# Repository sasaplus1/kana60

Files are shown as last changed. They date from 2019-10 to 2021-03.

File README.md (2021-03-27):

# kana60



JP layout 60% mechanical keyboard

<p align="center">
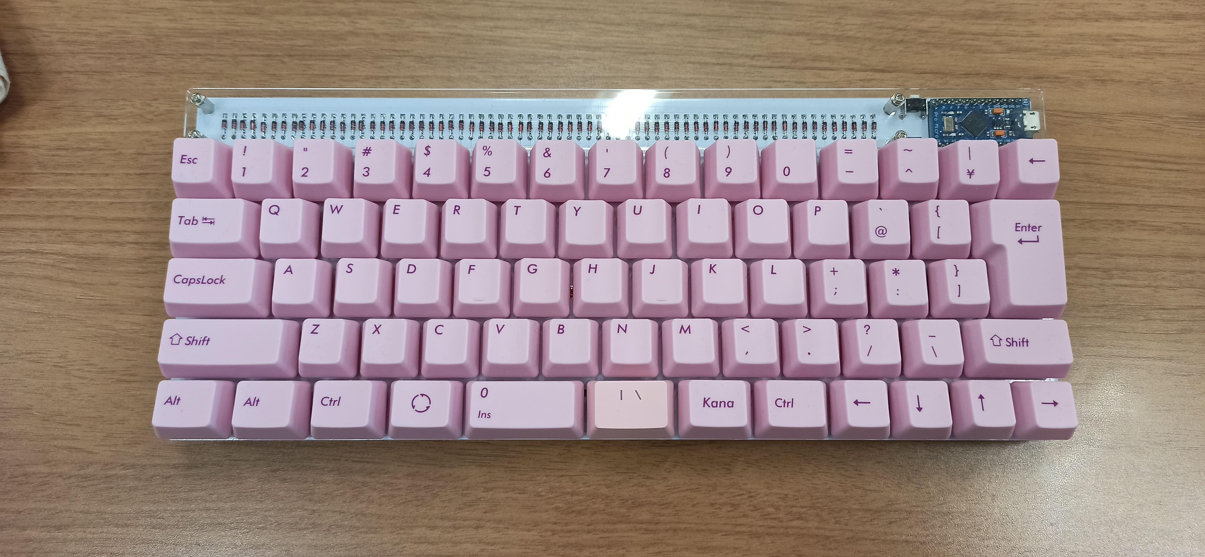
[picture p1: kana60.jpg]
kana60 keyboard
  
</p>

Keycaps: [FILCO FKCS108NMP](https://www.amazon.co.jp/dp/B07SR3NHXY/) and another 1 keycap (At bottom of N key).

QMK Firmware: [sasaplus1/qmk_firmware](https://github.com/qmk/qmk_firmware/compare/master...sasaplus1:kana60-test)

## How to verify checksums

```console
$ ls -1
kana60-acrylic-plates.zip
kana60-sha256sum.txt
kana60-top-plate.zip
kana60.zip
$ shasum --check kana60-sha256sum.txt
kana60-acrylic-plates.zip: OK
kana60.zip: OK
kana60-top-plate.zip: OK
```

## How to release

remove dist files:

```console
$ make clean
```

generate some files:

- open `kana60.kicad_pcb` and generate gerber files and drill files, via: `plot...`
- open `kana60-top-plate.kicad_pcb` and generate gerber files and drill files, via: `plot...`
- open `kana60-acrylic-plates.kicad_pcb` and generate PDF files, via: `plot...`

generate zip files and checksum file:

```console
$ make build create_checksum
```

verify zip files:

```console
$ make info
zipinfo dist/kana60-acrylic-plates/kana60-acrylic-plates.zip
Archive:  dist/kana60-acrylic-plates/kana60-acrylic-plates.zip
Zip file size: 22152 bytes, number of entries: 2
-rw-r--r--  3.0 unx     3150 bx defN 19-Oct-27 17:44 kana60-acrylic-plates-main.pdf
-rw-r--r--  3.0 unx    20236 bx defN 19-Oct-27 17:44 kana60-acrylic-plates-dimensions.pdf
2 files, 23386 bytes uncompressed, 21742 bytes compressed:  7.0%
zipinfo dist/kana60/kana60.zip
Archive:  dist/kana60/kana60.zip
Zip file size: 455650 bytes, number of entries: 9
-rw-r--r--  3.0 unx   807098 tx defN 19-Oct-27 17:44 kana60.GBL
-rw-r--r--  3.0 unx   293239 tx defN 19-Oct-27 17:44 kana60.GBS
-rw-r--r--  3.0 unx    49400 tx defN 19-Oct-27 17:44 kana60.GBO
-rw-r--r--  3.0 unx      980 tx defN 19-Oct-27 17:44 kana60.GML
-rw-r--r--  3.0 unx   522285 tx defN 19-Oct-27 17:44 kana60.GTL
-rw-r--r--  3.0 unx   293239 tx defN 19-Oct-27 17:44 kana60.GTS
-rw-r--r--  3.0 unx    88481 tx defN 19-Oct-27 17:44 kana60.GTO
-rw-r--r--  3.0 unx     4210 tx defN 19-Oct-27 17:44 kana60-NPTH.TXT
-rw-r--r--  3.0 unx    11536 tx defN 19-Oct-27 17:44 kana60.TXT
9 files, 2070468 bytes uncompressed, 454286 bytes compressed:  78.1%
zipinfo dist/kana60-top-plate/kana60-top-plate.zip
Archive:  dist/kana60-top-plate/kana60-top-plate.zip
Zip file size: 93042 bytes, number of entries: 9
-rw-r--r--  3.0 unx   201454 tx defN 19-Oct-27 17:44 kana60-top-plate.GBL
-rw-r--r--  3.0 unx     5359 tx defN 19-Oct-27 17:44 kana60-top-plate.GBS
-rw-r--r--  3.0 unx    11104 tx defN 19-Oct-27 17:44 kana60-top-plate.GBO
-rw-r--r--  3.0 unx    19886 tx defN 19-Oct-27 17:44 kana60-top-plate.GML
-rw-r--r--  3.0 unx   201454 tx defN 19-Oct-27 17:44 kana60-top-plate.GTL
-rw-r--r--  3.0 unx     5359 tx defN 19-Oct-27 17:44 kana60-top-plate.GTS
-rw-r--r--  3.0 unx      506 tx defN 19-Oct-27 17:44 kana60-top-plate.GTO
-rw-r--r--  3.0 unx      296 tx defN 19-Oct-27 17:44 kana60-top-plate-NPTH.TXT
-rw-r--r--  3.0 unx      388 tx defN 19-Oct-27 17:44 kana60-top-plate.TXT
9 files, 445806 bytes uncompressed, 91498 bytes compressed:  79.5%
```

push tag to GitHub and create Release:

```console
$ git tag 1.0
$ git push origin 1.0
```

upload files:

- kana60-acrylic-plates.zip
- kana60-sha256sum.txt
- kana60-top-plate.zip
- kana60.zip

## License

The MIT license.

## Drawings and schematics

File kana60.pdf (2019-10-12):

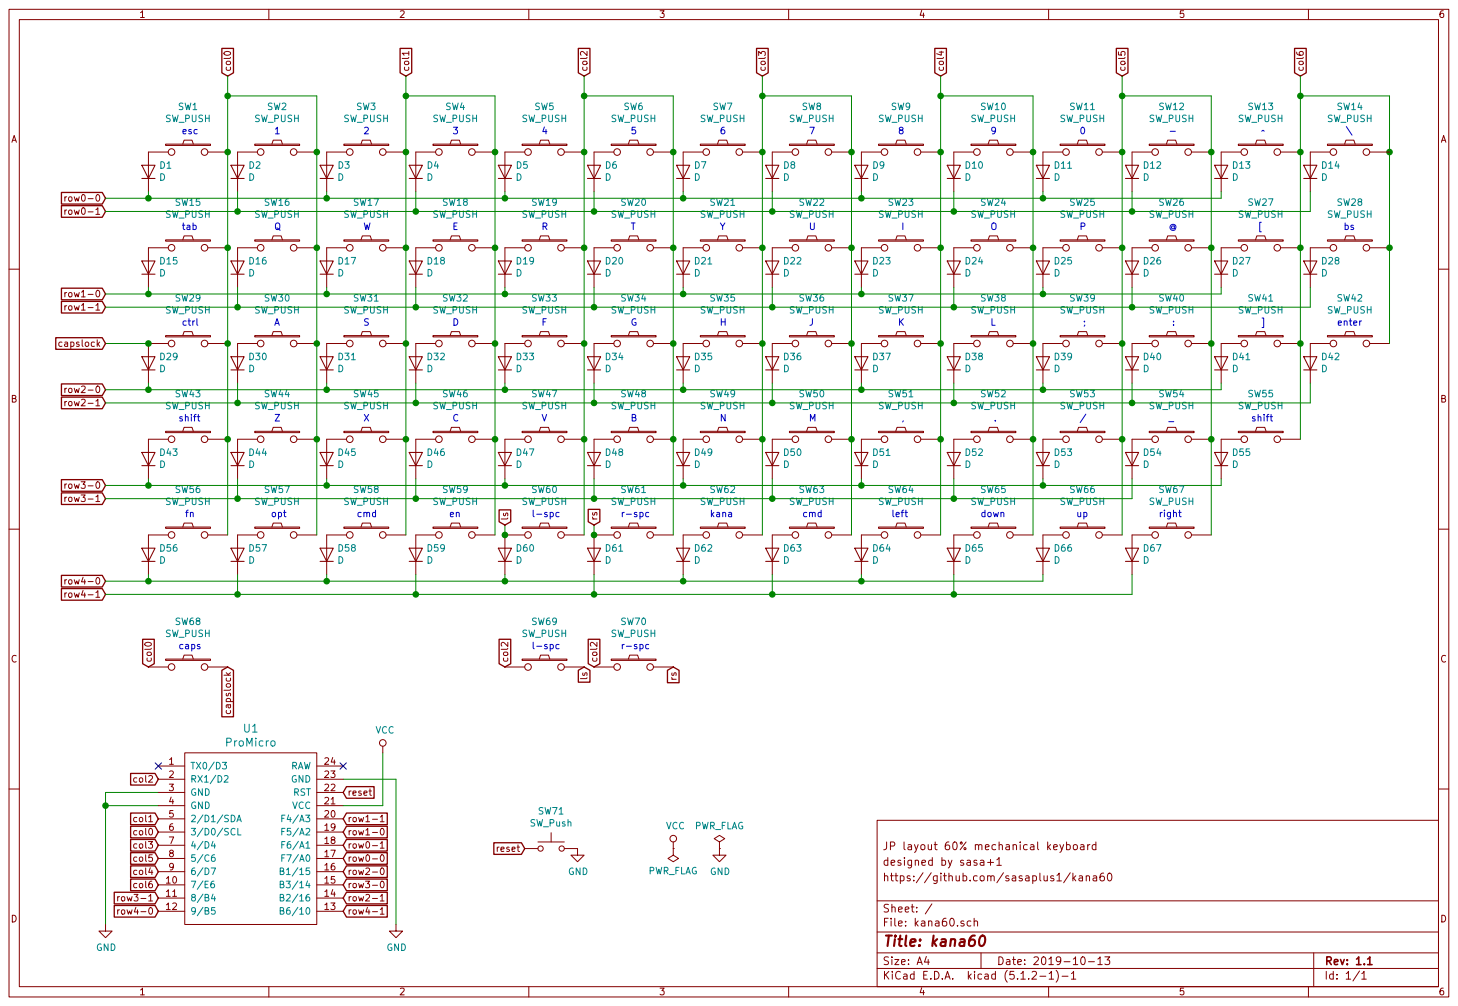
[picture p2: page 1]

JP layout 60% mechanical keyboard
designed by sasa+1
File: kana60.sch Sheet: / https://github.com/sasaplus1/kana60

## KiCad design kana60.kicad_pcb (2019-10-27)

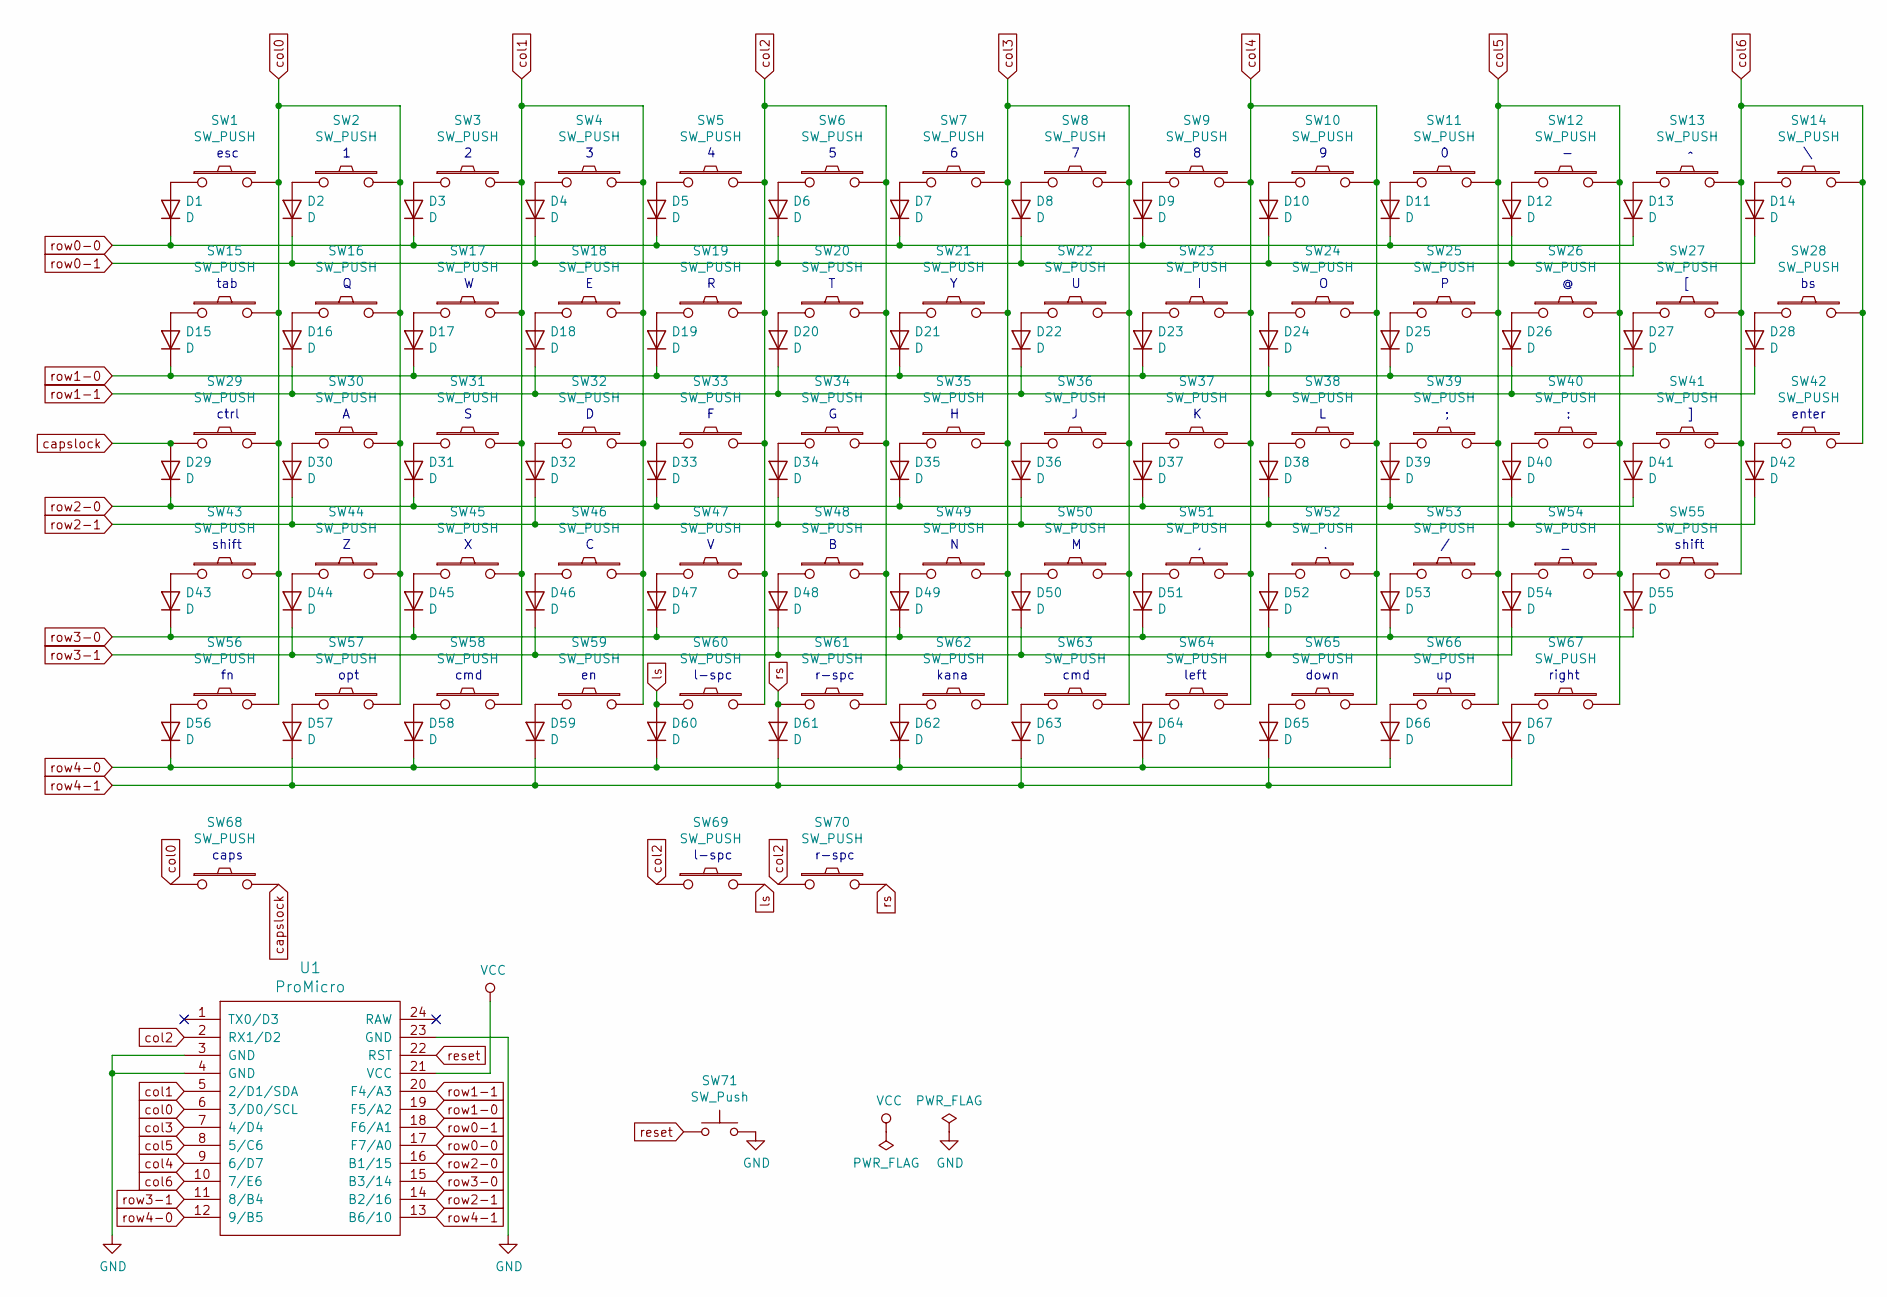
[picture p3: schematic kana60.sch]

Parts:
D1, D2, D3, D4, D5, D6, D7, D8, D9, D10, D11, D12, D13, D14, D15, D16, D17, D18, D19, D20, D21, D22, D23, D24, D25, D26, D27, D28, D29, D30, D31, D32, D33, D34, D35, D36, D37, D38, D39, D40, D41, D42, D43, D44, D45, D46, D47, D48, D49, D50, D51, D52, D53, D54, D55, D56, D57, D58, D59, D60, D61, D62, D63, D64, D65, D66, D67: D; diode
SW1, SW2, SW3, SW4, SW5, SW6, SW7, SW8, SW9, SW10, SW11, SW12, SW13, SW14, SW16, SW17, SW18, SW19, SW20, SW21, SW22, SW23, SW24, SW25, SW26, SW27, SW28, SW30, SW31, SW32, SW33, SW34, SW35, SW36, SW37, SW38, SW39, SW40, SW41, SW44, SW45, SW46, SW47, SW48, SW49, SW50, SW51, SW52, SW53, SW54, SW61, SW64, SW65, SW66, SW67, SW68, SW69: SW_PUSH; Hybrid_PCB_100H
SW15: SW_PUSH; Hybrid_PCB_150H
SW29, SW55: SW_PUSH; Hybrid_PCB_175H
SW42, SW43, SW60, SW70: SW_PUSH; Hybrid_PCB_200H
SW56, SW57, SW58, SW59, SW62, SW63: SW_PUSH; Hybrid_PCB_125H
SW71: SW_Push; SW_Tactile_SPST_Angled_MJTP1117
U1: ProMicro; ArduinoProMicro

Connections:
GND: SW71.2, U1.3 (GND), U1.4 (GND), U1.23 (GND)
unnamed: D1.2 (A), SW1.1
unnamed: D2.2 (A), SW2.1
unnamed: D3.2 (A), SW3.1
unnamed: D4.2 (A), SW4.1
unnamed: D5.2 (A), SW5.1
unnamed: D6.2 (A), SW6.1
unnamed: D7.2 (A), SW7.1
unnamed: D8.2 (A), SW8.1
unnamed: D9.2 (A), SW9.1
unnamed: D10.2 (A), SW10.1
unnamed: D11.2 (A), SW11.1
unnamed: D12.2 (A), SW12.1
unnamed: D13.2 (A), SW13.1
unnamed: D14.2 (A), SW14.1
unnamed: D15.2 (A), SW15.1
unnamed: D16.2 (A), SW16.1
unnamed: D17.2 (A), SW17.1
unnamed: D18.2 (A), SW18.1
unnamed: D19.2 (A), SW19.1
unnamed: D20.2 (A), SW20.1
unnamed: D21.2 (A), SW21.1
unnamed: D22.2 (A), SW22.1
unnamed: D23.2 (A), SW23.1
unnamed: D24.2 (A), SW24.1
unnamed: D25.2 (A), SW25.1
unnamed: D26.2 (A), SW26.1
unnamed: D27.2 (A), SW27.1
unnamed: D28.2 (A), SW28.1
unnamed: D30.2 (A), SW30.1
unnamed: D31.2 (A), SW31.1
unnamed: D32.2 (A), SW32.1
unnamed: D33.2 (A), SW33.1
unnamed: D34.2 (A), SW34.1
unnamed: D35.2 (A), SW35.1
unnamed: D36.2 (A), SW36.1
unnamed: D37.2 (A), SW37.1
unnamed: D38.2 (A), SW38.1
unnamed: D39.2 (A), SW39.1
unnamed: D40.2 (A), SW40.1
unnamed: D41.2 (A), SW41.1
unnamed: D42.2 (A), SW42.1
unnamed: D43.2 (A), SW43.1
unnamed: D44.2 (A), SW44.1
unnamed: D45.2 (A), SW45.1
unnamed: D46.2 (A), SW46.1
unnamed: D47.2 (A), SW47.1
unnamed: D48.2 (A), SW48.1
unnamed: D49.2 (A), SW49.1
unnamed: D50.2 (A), SW50.1
unnamed: D51.2 (A), SW51.1
unnamed: D52.2 (A), SW52.1
unnamed: D53.2 (A), SW53.1
unnamed: D54.2 (A), SW54.1
unnamed: D55.2 (A), SW55.1
unnamed: D56.2 (A), SW56.1
unnamed: D57.2 (A), SW57.1
unnamed: D58.2 (A), SW58.1
unnamed: D59.2 (A), SW59.1
unnamed: D62.2 (A), SW62.1
unnamed: D63.2 (A), SW63.1
unnamed: D64.2 (A), SW64.1
unnamed: D65.2 (A), SW65.1
unnamed: D66.2 (A), SW66.1
unnamed: D67.2 (A), SW67.1
VCC: U1.21 (VCC)
capslock: D29.2 (A), SW29.1, SW68.2
col0: SW1.2, SW2.2, SW15.2, SW16.2, SW29.2, SW30.2, SW43.2, SW44.2, SW56.2, SW57.2, SW68.1, U1.6 (3/D0/SCL)
col1: SW3.2, SW4.2, SW17.2, SW18.2, SW31.2, SW32.2, SW45.2, SW46.2, SW58.2, SW59.2, U1.5 (2/D1/SDA)
col2: SW5.2, SW6.2, SW19.2, SW20.2, SW33.2, SW34.2, SW47.2, SW48.2, SW60.2, SW61.2, SW69.1, SW70.1, U1.2 (RX1/D2)
col3: SW7.2, SW8.2, SW21.2, SW22.2, SW35.2, SW36.2, SW49.2, SW50.2, SW62.2, SW63.2, U1.7 (4/D4)
col4: SW9.2, SW10.2, SW23.2, SW24.2, SW37.2, SW38.2, SW51.2, SW52.2, SW64.2, SW65.2, U1.9 (6/D7)
col5: SW11.2, SW12.2, SW25.2, SW26.2, SW39.2, SW40.2, SW53.2, SW54.2, SW66.2, SW67.2, U1.8 (5/C6)
col6: SW13.2, SW14.2, SW27.2, SW28.2, SW41.2, SW42.2, SW55.2, U1.10 (7/E6)
ls: D60.2 (A), SW60.1, SW69.2
reset: SW71.1, U1.22 (RST)
row0-0: D1.1 (K), D3.1 (K), D5.1 (K), D7.1 (K), D9.1 (K), D11.1 (K), D13.1 (K), U1.17 (F7/A0)
row0-1: D2.1 (K), D4.1 (K), D6.1 (K), D8.1 (K), D10.1 (K), D12.1 (K), D14.1 (K), U1.18 (F6/A1)
row1-0: D15.1 (K), D17.1 (K), D19.1 (K), D21.1 (K), D23.1 (K), D25.1 (K), D27.1 (K), U1.19 (F5/A2)
row1-1: D16.1 (K), D18.1 (K), D20.1 (K), D22.1 (K), D24.1 (K), D26.1 (K), D28.1 (K), U1.20 (F4/A3)
row2-0: D29.1 (K), D31.1 (K), D33.1 (K), D35.1 (K), D37.1 (K), D39.1 (K), D41.1 (K), U1.16 (B1/15)
row2-1: D30.1 (K), D32.1 (K), D34.1 (K), D36.1 (K), D38.1 (K), D40.1 (K), D42.1 (K), U1.14 (B2/16)
row3-0: D43.1 (K), D45.1 (K), D47.1 (K), D49.1 (K), D51.1 (K), D53.1 (K), D55.1 (K), U1.15 (B3/14)
row3-1: D44.1 (K), D46.1 (K), D48.1 (K), D50.1 (K), D52.1 (K), D54.1 (K), U1.11 (8/B4)
row4-0: D56.1 (K), D58.1 (K), D60.1 (K), D62.1 (K), D64.1 (K), D66.1 (K), U1.12 (9/B5)
row4-1: D57.1 (K), D59.1 (K), D61.1 (K), D63.1 (K), D65.1 (K), D67.1 (K), U1.13 (B6/10)
rs: D61.2 (A), SW61.1, SW70.2

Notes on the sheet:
esc
tab
ctrl
shift
opt
cmd
l-spc
kana
left
down
right
enter
r-spc
caps

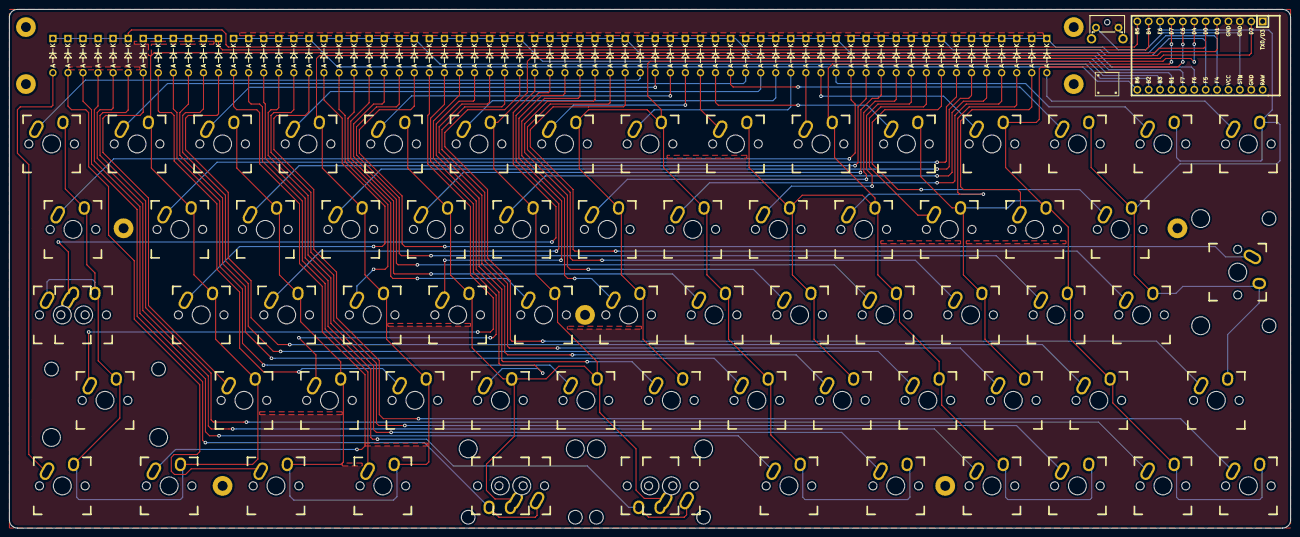
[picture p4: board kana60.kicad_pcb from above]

Board: 2 copper layers, 285.5 x 115.6 mm, 148 parts (0 on the bottom side), 86 nets.

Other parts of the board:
REF1, REF2, REF3, REF4, REF5, REF6, REF7, REF8, REF9: MountingHole_2.2mm_M2_Pad

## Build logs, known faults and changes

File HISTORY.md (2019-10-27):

# rev.1.1 / 2019-10-27

## PCB

- flip upside down space key switches
    - fix wobble to stabilizer
- update wiring
    - improve GND plane
- update icon size and position
- update label size and position
- change tactile switch to MJTP1117 from ResetSW
    - I think I can use TSZJ36H or COM-10791 maybe

## Top plate

- add icon
- add label
- update shift, enter and space keys
    - improve for stabilizer to smooth action

## Acrylic plates

- nothing

# rev.1.0 / 2019-10-05

- initial release

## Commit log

2019-06-16 create KiCad project
    [kana60.kicad_pcb, kana60.sch]
2019-06-18 add KiCad files
2019-06-18 add ProMicro and reset switch
    [kana60.sch]
2019-06-30 add key switches
    [kana60.sch]
2019-06-30 annotation and rule check
    [kana60.sch]
2019-06-30 fix footprint
    [kana60.sch]
2019-07-01 add PCB footprint
    [kana60.sch]
2019-07-02 update label
    [kana60.sch]
2019-07-04 remove extra diode
    [kana60.sch]
2019-07-05 change footprint
    [kana60.sch]
2019-07-07 add footprint
2019-07-07 update schematic
    [kana60.sch]
2019-07-07 update pcb
    [kana60.kicad_pcb]
2019-07-24 remove footprint
2019-07-24 update footprint
    [kana60.kicad_pcb, kana60.sch]
2019-07-30 add trace width
    [kana60.kicad_pcb]
2019-07-30 fix schematic
    [kana60.sch]
2019-08-01 change to use through hole diode
    [kana60.sch]
2019-09-25 trial and error
    [kana60.kicad_pcb]
2019-09-25 connection complete
    [kana60.kicad_pcb]
2019-09-25 rotate reset switch
    [kana60.kicad_pcb]
2019-09-25 add text
    [kana60.kicad_pcb]
2019-09-25 hide silks
    [kana60.kicad_pcb]
2019-09-25 add logo
    [kana60.kicad_pcb]
2019-09-25 add title
    [kana60.kicad_pcb]
2019-09-25 reassign grid origin
    [kana60.kicad_pcb]
2019-09-28 add footprints
2019-09-28 move local footprints
2019-09-28 update netlist
    [kana60.sch]
2019-09-28 update footprints
    [kana60.kicad_pcb]
2019-09-28 move icon position
    [kana60.kicad_pcb]
2019-09-28 add top plate
    [kana60-top-plate.kicad_pcb]
2019-09-28 remove extra footprints
    [kana60-top-plate.kicad_pcb]
2019-09-29 update top plate
    [kana60-top-plate.kicad_pcb]
2019-09-29 add acrylic plates
    [kana60-acrylic-plates.kicad_pcb]
2019-09-29 add bottom acrylic plate
    [kana60-acrylic-plates.kicad_pcb]
2019-09-30 update acrylic plates
    [kana60-acrylic-plates.kicad_pcb]
2019-10-02 rewrite Edge.Cuts
    [kana60.kicad_pcb]
2019-10-02 change to Cmts.User from Dwgs.User
    [kana60.kicad_pcb]
2019-10-02 add dimention lines
    [kana60-acrylic-plates.kicad_pcb]
2019-10-02 add GND plane
    [kana60.kicad_pcb]
2019-10-03 trim anntena
    [kana60.kicad_pcb]
2019-10-03 update output directory
    [kana60.kicad_pcb]
2019-10-04 update dimention lines
    [kana60-acrylic-plates.kicad_pcb]
2019-10-04 move lines into frame
    [kana60-acrylic-plates.kicad_pcb]
2019-10-12 add plane to top plate
    [kana60-top-plate.kicad_pcb]
2019-10-12 change revision to 1.1 from 1.0
    [kana60-acrylic-plates.kicad_pcb, kana60-top-plate.kicad_pcb, kana60.kicad_pcb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]
2019-10-24 fix stabilizer interfere
    [kana60-top-plate.kicad_pcb]
2019-10-24 update captions
    [kana60.kicad_pcb]
2019-10-26 add label to top plate
    [kana60-top-plate.kicad_pcb]
2019-10-26 add icon to top plate
    [kana60-top-plate.kicad_pcb]
2019-10-26 update icon
    [kana60.kicad_pcb]
2019-10-26 update GND plane
    [kana60.kicad_pcb]
2019-10-26 change tactile button
    [kana60.kicad_pcb, kana60.sch]
2019-10-26 rotate space bar switches for fix stabilizer
    [kana60.kicad_pcb]
2019-10-27 update GND plane and wiring
    [kana60.kicad_pcb]
